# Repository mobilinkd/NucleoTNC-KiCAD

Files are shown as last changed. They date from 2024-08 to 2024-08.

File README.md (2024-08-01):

# NucleoTNC KiCAD Files

This repository contains the KiCAD files for the NucleoTNC PCB, the spacer
needed to mount the Nucleo32 board at the proper height for the enclosure,
and the two enclosure encaps.

This is project is Open Source Hardware.

These files are licensed under the CERN Open Hardware Licence version 2
(CERN-OHL-S). Please see the [LICENSE](LICENSE) file for details. Note that
this license only covers the hardware in this repository. The firmware for
the NucleoTNC is licensed separately under the GPLv3.

These files are currently for KiCAD version 7.

# NucleoTNC PCB and Spacer

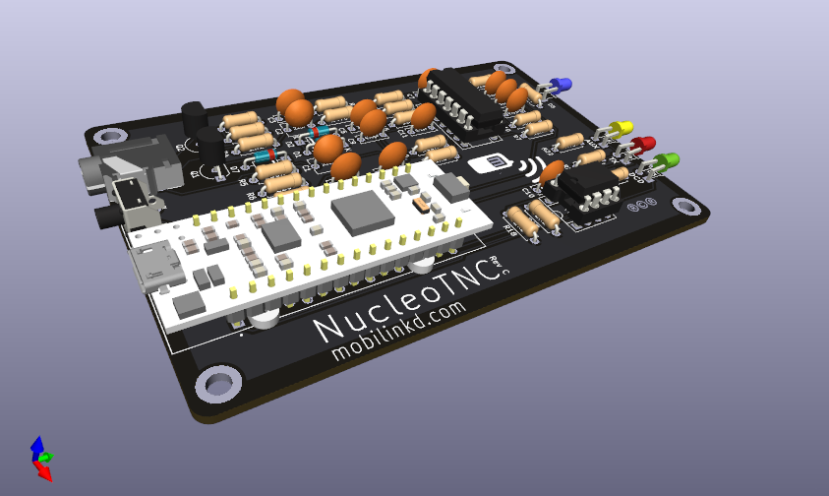
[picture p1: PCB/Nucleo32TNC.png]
NucleoTNC PCB and Spacer


The NucleoTNC is a breadboard TNC project that reproduced most of the
features of the Mobilinkd TNC3. I just lacked a battery and Bluetooth
support. It was and remains a very popular project build for ham radio
operators.

This PCB was designed to allow experimenters that wanted a more permanent
home for their TNC to move the components onto a PCB. The PCB is designed
with a special pin pattern that will securely hold the ST Microelectronics
Nucleo32 board without a socket or soldering.

The spacer is designed to hold the Nucleo32 module off of the PCB at the
correct height to fit in the enclosure. It can either be made as a PCB out
of FR-4 material or 3D-printed using any non-conductive material.

# NucleoTNC Front and Back Panel

The front and back panels are designed for use with the Szomk AK-C-C15 100mm
aluminum enclosure. This will require 8 M2.5 screws. We use stainless steel
socket-cap screws for this.

# Kits For Sale

The PCB and spacer, and the complete enclosure can be purchased online
from Mobilinkd. https://store.mobilinkd.com/collections/kits

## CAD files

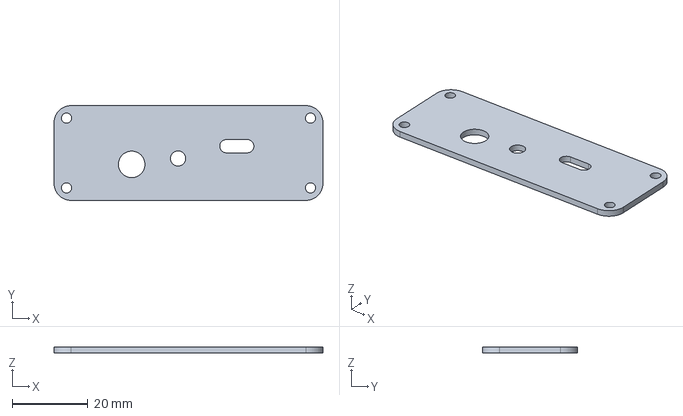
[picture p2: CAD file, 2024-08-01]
BackPanel/BackPanelRevB.step
71.0 x 25.0 x 1.60 mm

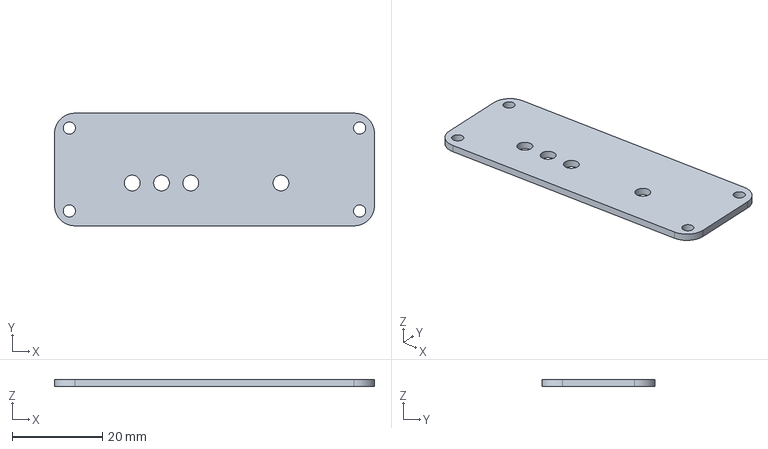
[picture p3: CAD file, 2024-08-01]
FrontPanel/FrontPanelRevB.step
71.0 x 25.0 x 1.60 mm

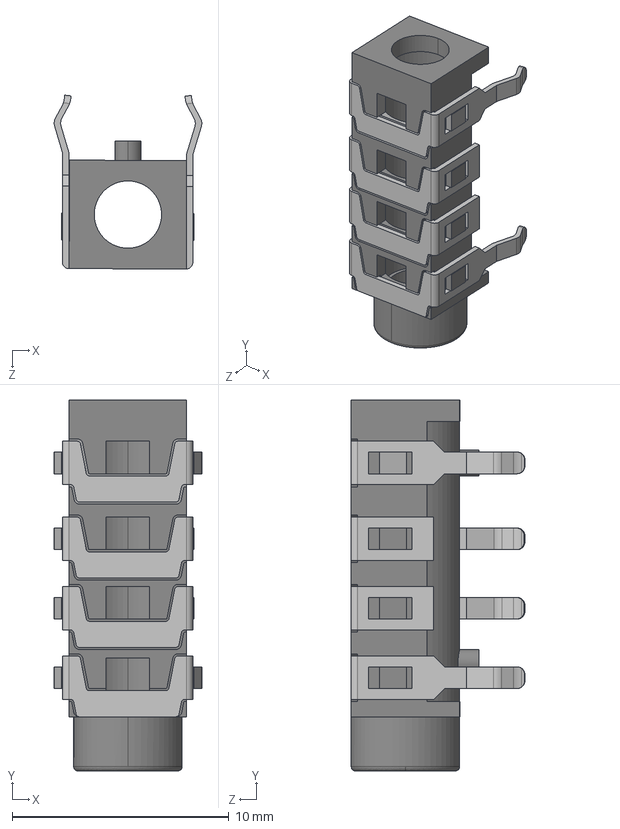
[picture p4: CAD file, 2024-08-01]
PCB/TRS Jack PJ-313B.STEP
6.81 x 17.1 x 8.02 mm

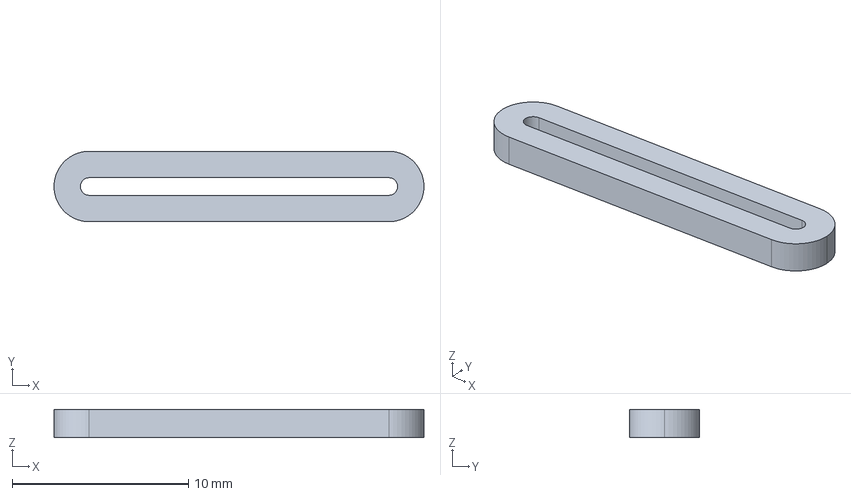
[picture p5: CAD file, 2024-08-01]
Spacer/Spacer.step
21.0 x 4.00 x 1.60 mm

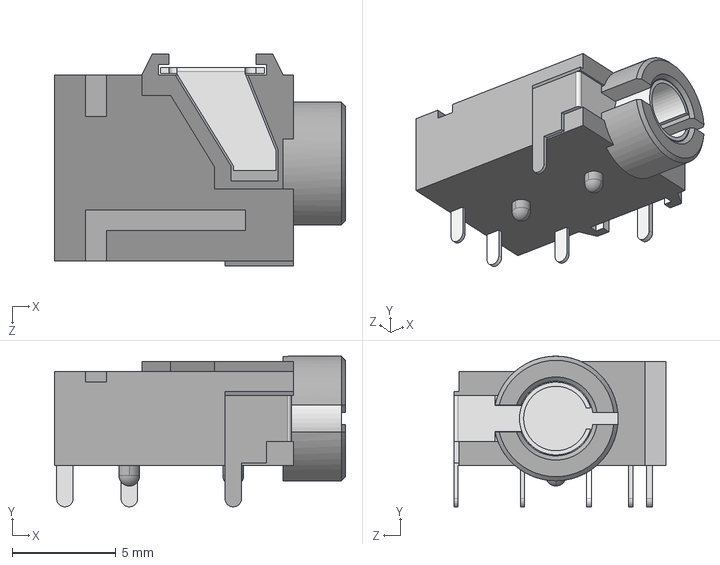
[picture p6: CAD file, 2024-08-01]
PCB/CUI_DEVICES_SJ-43515TS.step
14.0 x 7.25 x 10.2 mm

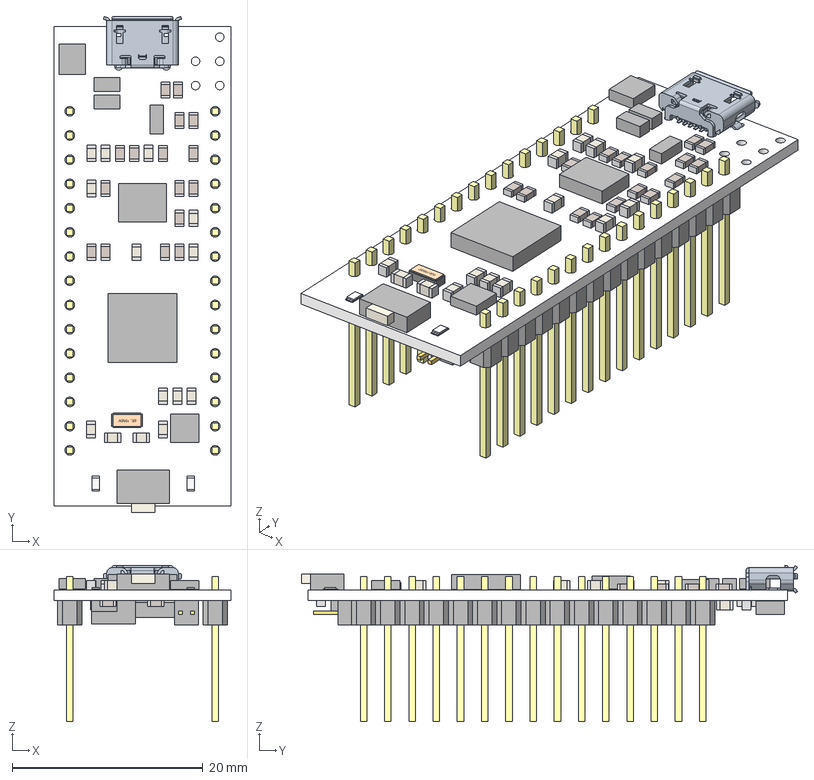
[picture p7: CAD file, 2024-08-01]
PCB/MB1180.step
18.5 x 52.0 x 16.4 mm
Extruded x 232
ABS07-120

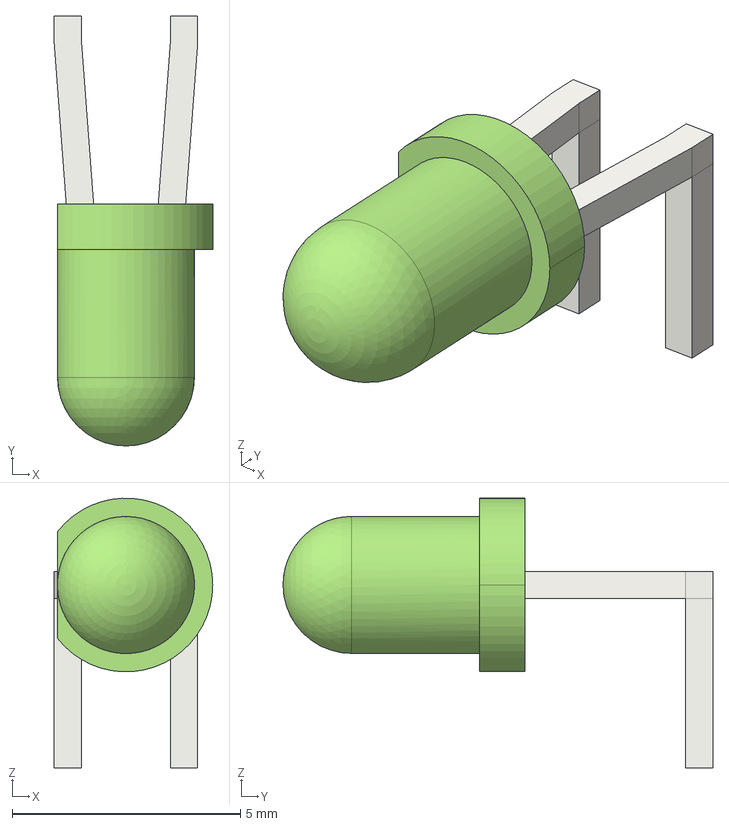
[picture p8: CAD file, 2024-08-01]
PCB/led_green.step
3.47 x 9.41 x 5.90 mm

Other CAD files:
PCB/led_blue.step
PCB/led_yellow.step
PCB/led_red.step

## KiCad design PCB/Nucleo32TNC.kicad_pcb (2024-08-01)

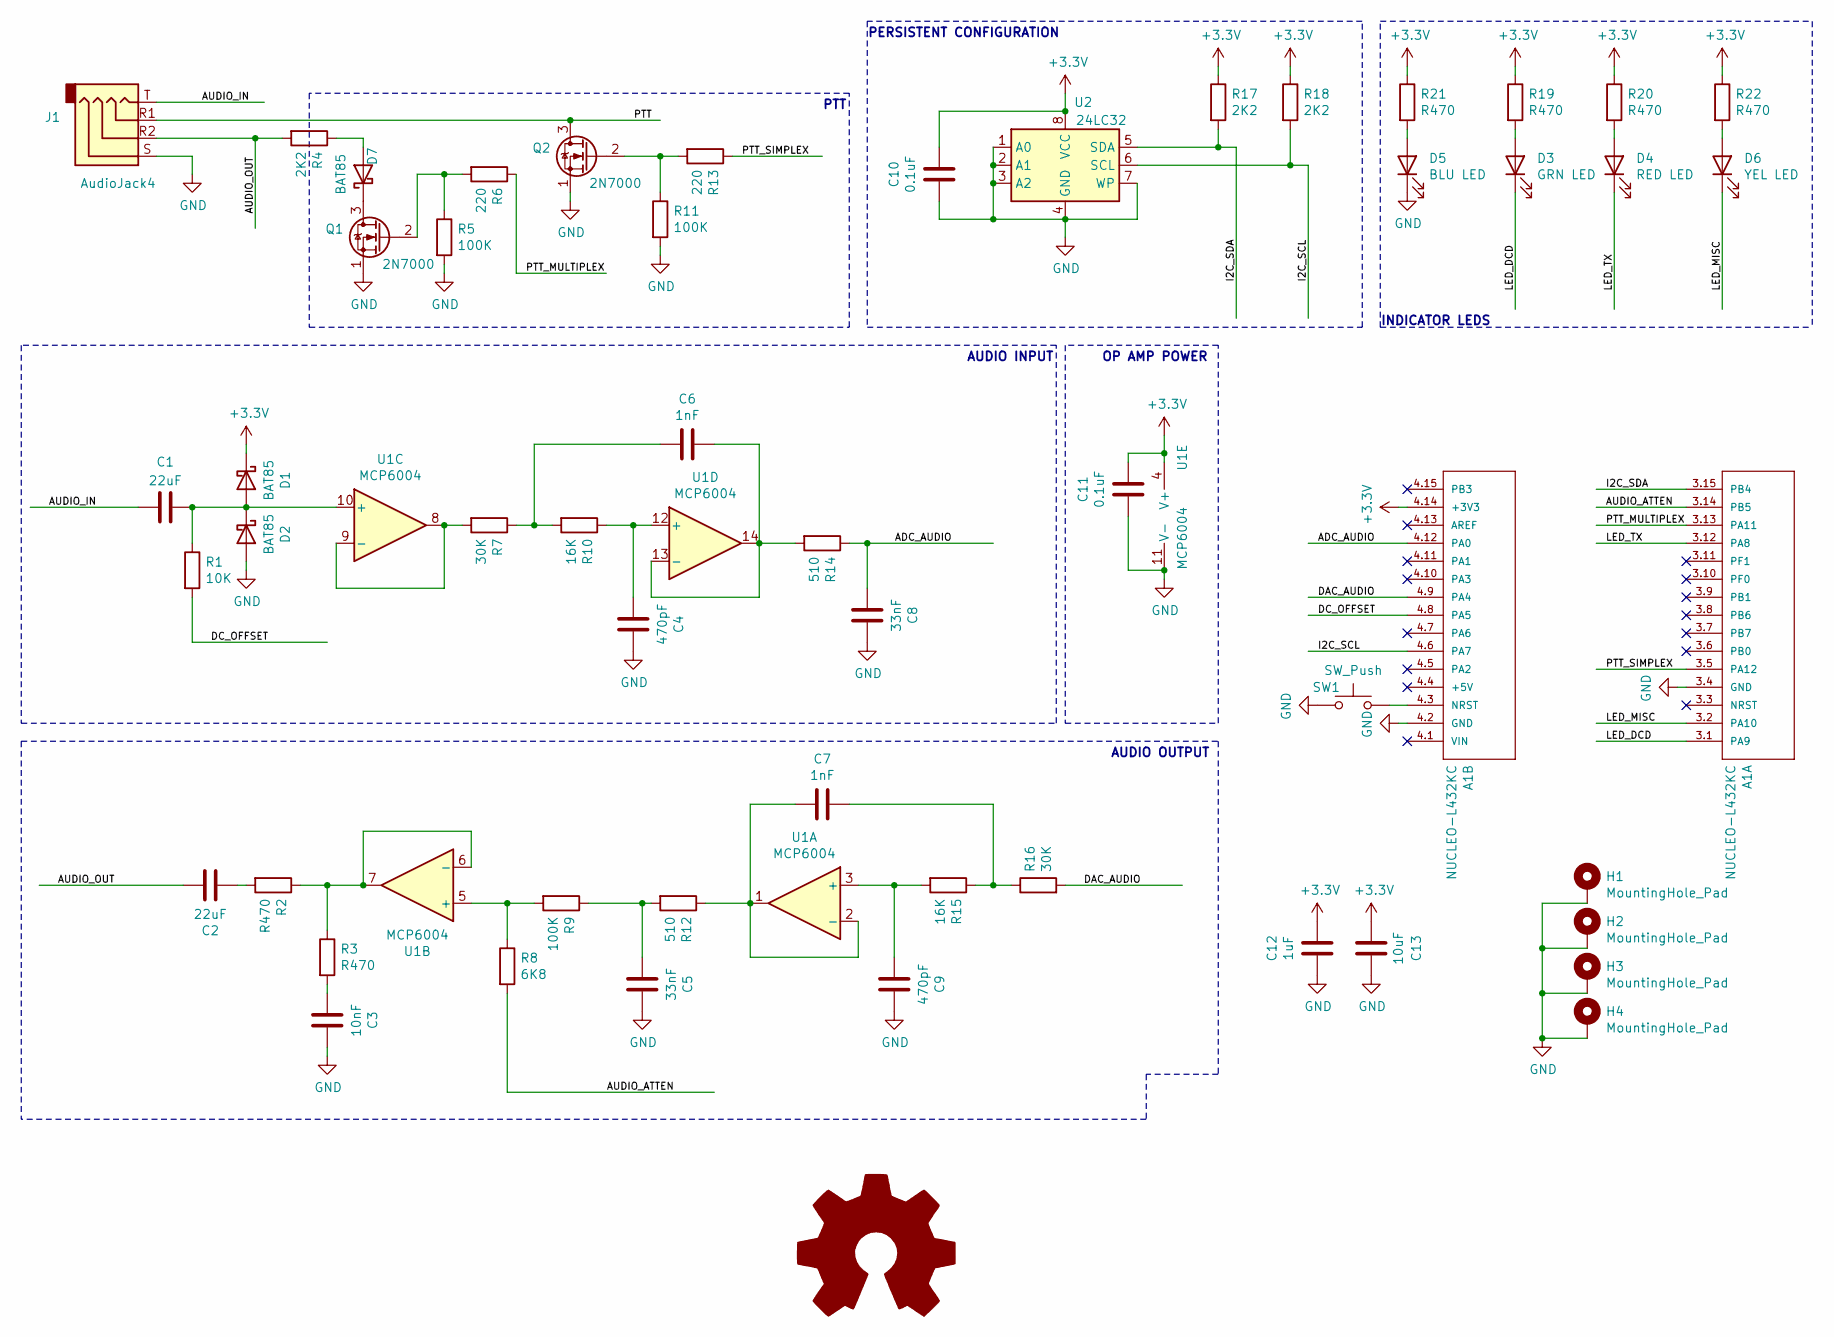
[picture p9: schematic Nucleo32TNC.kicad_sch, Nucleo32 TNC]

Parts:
A1: NUCLEO-L432KC; MODULE_NUCLEO-F303K8
C1, C2: 22uF; C_Disc_D6.0mm_W4.4mm_P5.00mm
C3: 10nF; C_Disc_D6.0mm_W2.5mm_P5.00mm
C4, C9: 470pF; C_Disc_D6.0mm_W2.5mm_P5.00mm
C5, C8: 33nF; C_Disc_D6.0mm_W2.5mm_P5.00mm
C6, C7: 1nF; C_Disc_D6.0mm_W2.5mm_P5.00mm
C10, C11: 0.1uF; C_Disc_D6.0mm_W2.5mm_P5.00mm
C12: 1uF; C_Disc_D6.0mm_W2.5mm_P5.00mm
C13: 10uF; C_Disc_D6.0mm_W2.5mm_P5.00mm
D1, D2, D7: BAT85; D_DO-35_SOD27_P7.62mm_Horizontal
D3: GRN LED; LED_D3.0mm_Horizontal_O3.81mm_Z2.0mm
D4: RED LED; LED_D3.0mm_Horizontal_O3.81mm_Z2.0mm
D5: BLU LED; LED_D3.0mm_Horizontal_O3.81mm_Z2.0mm
D6: YEL LED; LED_D3.0mm_Horizontal_O3.81mm_Z2.0mm
H1, H2, H3, H4: MountingHole_Pad; MountingHole_3.2mm_M3_ISO14580_Pad
J1: AudioJack4; CUI_SJ-43515TS
Q1, Q2: 2N7000; TO-92_Inline_Wide
R1: 10K; R_Axial_DIN0207_L6.3mm_D2.5mm_P7.62mm_Horizontal
R2, R3, R19, R20, R21, R22: R470; R_Axial_DIN0207_L6.3mm_D2.5mm_P7.62mm_Horizontal
R4, R17, R18: 2K2; R_Axial_DIN0207_L6.3mm_D2.5mm_P7.62mm_Horizontal
R5, R9, R11: 100K; R_Axial_DIN0207_L6.3mm_D2.5mm_P7.62mm_Horizontal
R6, R13: 220; R_Axial_DIN0207_L6.3mm_D2.5mm_P7.62mm_Horizontal
R7, R16: 30K; R_Axial_DIN0207_L6.3mm_D2.5mm_P7.62mm_Horizontal
R8: 6K8; R_Axial_DIN0207_L6.3mm_D2.5mm_P7.62mm_Horizontal
R10, R15: 16K; R_Axial_DIN0207_L6.3mm_D2.5mm_P7.62mm_Horizontal
R12, R14: 510; R_Axial_DIN0207_L6.3mm_D2.5mm_P7.62mm_Horizontal
SW1: SW_Push; SW_Tactile_SPST_Angled_PTS645Vx58-2LFS
U1: MCP6004; DIP-14_W7.62mm_Socket
U2: 24LC32; DIP-8_W7.62mm_Socket

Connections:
+3V3: A1.4.14 (+3V3), C10.1, C11.1, C12.1, C13.1, D1.1 (K), R17.1, R18.1, R19.1, R20.1, R21.1, R22.1, U1.4 (V+), U2.8 (VCC)
/ADC_AUDIO: A1.4.12 (PA0), C8.2, R14.1
/AUDIO_ATTEN: A1.3.14 (PB5), R8.2
/AUDIO_IN: C1.2, J1.T
/AUDIO_OUT: C2.1, J1.R2, R4.2
/DAC_AUDIO: A1.4.9 (PA4), R16.2
/DC_OFFSET: A1.4.8 (PA5), R1.2
/I2C_SCL: A1.4.6 (PA7), R18.2, U2.6 (SCL)
/I2C_SDA: A1.3.15 (PB4), R17.2, U2.5 (SDA)
/LED_DCD: A1.3.1 (PA9), D3.1 (K)
/LED_MISC: A1.3.2 (PA10), D6.1 (K)
/LED_TX: A1.3.12 (PA8), D4.1 (K)
/PTT: J1.R1, Q2.3 (D)
/PTT_MULTIPLEX: A1.3.13 (PA11), R6.1
/PTT_SIMPLEX: A1.3.5 (PA12), R13.1
GND: A1.3.4 (GND), A1.4.2 (GND), C3.1, C4.1, C5.1, C8.1, C9.1, C10.2, C11.2, C12.2, C13.2, D2.2 (A), D5.1 (K), H1.1, H2.1, H3.1, H4.1, J1.S, Q1.1 (S), Q2.1 (S), R5.2, R11.2, SW1.1, U1.11 (V-), U2.1 (A0), U2.2 (A1), U2.3 (A2), U2.4 (GND), U2.7 (WP)
unnamed: A1.4.3 (NRST), SW1.2
unnamed: C2.2, R2.2
unnamed: C3.2, R3.2
unnamed: C5.2, R9.1, R12.2
unnamed: C6.2, R7.1, R10.2
unnamed: C7.1, R15.1, R16.1
unnamed: C1.1, D1.2 (A), D2.1 (K), R1.1, U1.10 (+)
unnamed: D3.2 (A), R19.2
unnamed: D4.2 (A), R20.2
unnamed: D5.2 (A), R21.2
unnamed: D6.2 (A), R22.2
unnamed: D7.2 (A), R4.1
unnamed: D7.1 (K), Q1.3 (D)
unnamed: Q1.2 (G), R5.1, R6.2
unnamed: Q2.2 (G), R11.1, R13.2
unnamed: C9.2, R15.2, U1.3 (+)
unnamed: C7.2, R12.1, U1.1, U1.2 (-)
unnamed: R8.1, R9.2, U1.5 (+)
unnamed: R2.1, R3.1, U1.6 (-), U1.7
unnamed: R7.2, U1.8, U1.9 (-)
unnamed: C4.2, R10.1, U1.12 (+)
unnamed: C6.1, R14.2, U1.13 (-), U1.14

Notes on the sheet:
AUDIO OUTPUT
PTT
AUDIO INPUT
INDICATOR LEDS
PERSISTENT CONFIGURATION
OP AMP POWER

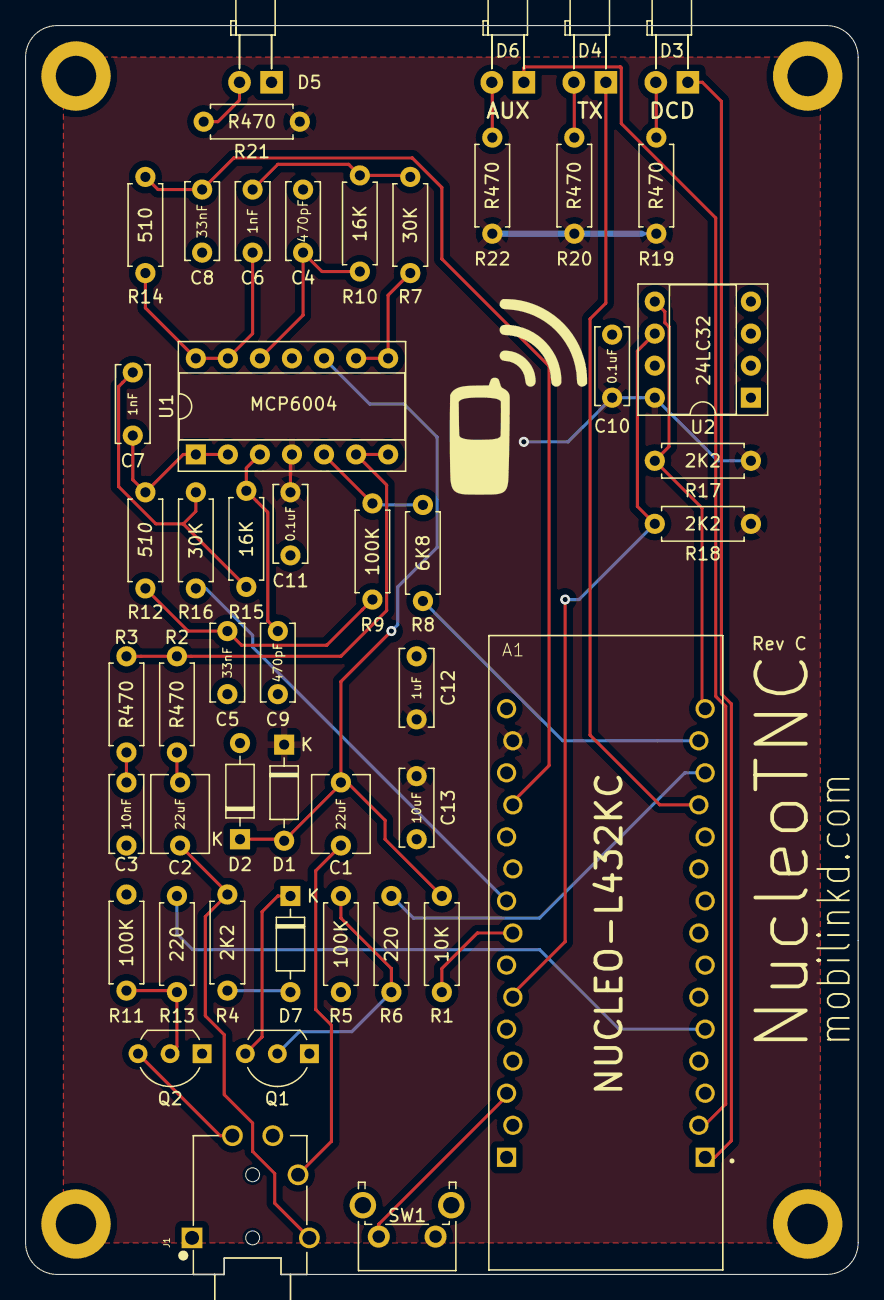
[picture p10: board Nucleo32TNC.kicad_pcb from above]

Board: 2 copper layers, 66.0 x 99.0 mm, 54 parts (0 on the bottom side), 38 nets.

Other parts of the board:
G1: LOGO

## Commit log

2019-06-23 Add KiCAD files and build instructions.
    [Nucleo32TNC.kicad_pcb, Nucleo32TNC.sch]
2020-03-16 Add new 60mm PCB.
    [CUI_DEVICES_SJ-43515TS.step, MB1180.step, Nucleo32TNC.sch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]
2020-03-16 Save PCB with KiCAD 5.1.5 (stable).
    [Nucleo32TNC.kicad_pcb]
2020-05-06 Rev B of 67mm board. Fix logo, move blue LED a bit, update C1 value, and expand Nucleo pin offsets for press-fit. Fix hole locations and significant alignment issues in front and rear panels. Change 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
    [BackPanel.kicad_pcb, BackPanel.sch, BackPanelRevB.step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]
2020-05-06 Update the rev on the pcb notes. Remove backup files. Update .gitignore for KiCAD files.
    [BackPanel.kicad_pcb, FrontPanel.kicad_pcb, Spacer.kicad_pcb]
2020-05-06 Update schematic C1 and add dimensions for mounting holes to PCB.
    [Nucleo32TNC.kicad_pcb, Nucleo32TNC.sch]
2020-05-08 Add fabrication notes to indicate where to place production codes.
    [BackPanel.kicad_pcb, FrontPanel.kicad_pcb, Nucleo32TNC.kicad_pcb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]
2020-12-07 Add gerbers.
    [BackPanel-B_Cu.gbr, BackPanel-B_Fab.gbr, BackPanel-B_Mask.gbr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]
2021-01-03 Update documentation and make one small part change to improve 9600 baud and M17 decode performance.
    [Nucleo32TNC.sch]
2021-07-17 Add Schottky diode on AUDIO OUT to eliminate the DC bias caused by Q1 body diode and C2.
    [Nucleo32TNC.sch]
2021-07-17 Use wide footprint for Q1 and Q2 to help with hand soldering.
    [Nucleo32TNC.sch]
2021-07-18 Update C1 & C2 values to 22uF and footprint size. Update decoupling capacitor footprints.
    [Nucleo32TNC.sch]
2021-07-18 Use larger footprints for C12 and C13.
    [Nucleo32TNC.sch]
2021-07-18 Update to Rev C.
    [Nucleo32TNC.sch]
2021-07-18 Update PCB to Rev C. Larger footprints for C1, C2, C10, C11, C12, C13, Q1, & Q2. Add new diode D7.
    [Nucleo32TNC.kicad_pcb]
2021-07-18 Fix a small silkscreen error. Move part designators for op amp, EEPROM and Nucleo board to silkscreen.
    [Nucleo32TNC-B_Cu.gbr, Nucleo32TNC-B_Mask.gbr, Nucleo32TNC-B_SilkS.gbr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]
2022-02-20 Add BOM for rev C PCB.
2024-08-01 Reorganize repo.
    [BackPanel-B_Cu.gbr, BackPanel-B_Fab.gbr, BackPanel-B_Mask.gbr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]
2024-08-01 Update files to KiCAD 7.
    [Nucleo32TNC.kicad_pcb, Nucleo32TNC.kicad_sch, Spacer.kicad_pcb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]
